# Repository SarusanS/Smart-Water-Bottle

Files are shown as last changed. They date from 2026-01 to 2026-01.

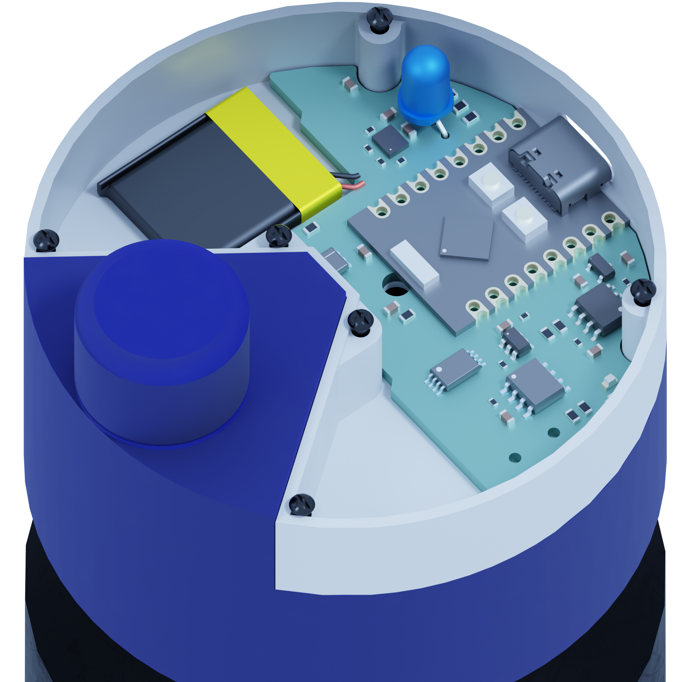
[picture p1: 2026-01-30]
RendersImaes_2/11.png

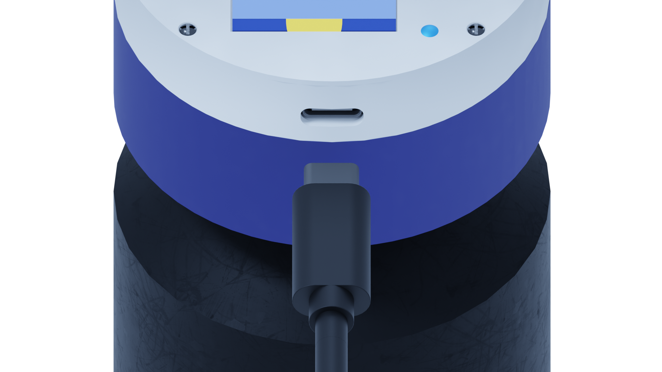
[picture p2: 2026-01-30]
RendersImages_1/6.png

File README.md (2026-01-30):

# Project Highlight | Product Design – Smart Water Bottle

This project presents a **standalone Smart Water Bottle** developed as part of a **Product Design course**, focused on accurate, motion-aware water consumption monitoring under real-world usage conditions such as **movement, refilling, and power interruptions**.

The system is **fully embedded** and operates independently **without requiring a mobile application**, prioritizing **reliability, usability, and data integrity**.

---

## System Functionality

Water consumption is monitored by tracking changes in liquid level using a **VL53L0X Time-of-Flight (ToF) distance sensor**. Instead of relying on the absolute bottle capacity, the system calculates consumed volume based on **successive stable distance measurements**, allowing cumulative tracking across multiple refill cycles.

Even if the physical bottle capacity is limited (e.g., **1 litre**), users can configure daily intake goals of **5 L, 10 L, or 15 L**. Each refill is automatically detected as an **increase in water level**, while subsequent decreases are accumulated to compute **total consumption over time**.  
This approach enables **continuous and scalable intake monitoring**, independent of bottle size.

---

## Motion-Aware Validation

To ensure measurement accuracy, the system integrates a **BMI270 Inertial Measurement Unit (IMU)** combined with a **Madgwick sensor fusion filter**.

- Distance measurements are accepted only when the bottle is **upright and stable**
- **Tilt, motion, shaking, lifting, and refilling events** are detected and filtered out
- A **stability verification delay** ensures readings are taken only after motion has fully stopped

This motion-aware logic prevents **false volume calculations** and significantly improves measurement reliability during **daily use**.

---

## Floating Reflective Marker for Accurate Measurement

To overcome the challenges of measuring water level in transparent containers, a **floating reflective marker** is used:

- A small **floating rubber disc** is placed directly on the water surface
- The ToF sensor reflects off the **rubber surface instead of the water itself**
- This avoids errors caused by **ripples, bubbles, refraction, or transparent bottle walls**

As the marker naturally follows the water surface, the system achieves **consistent and repeatable distance measurements**, which are converted into volume through **firmware-level calculations**.

---

## Operating Modes

### Mode 1 – Goal-Based Tracking
- User-configurable **daily intake goal**
- Tracks **daily water consumption**
- Automatically **resets every 24 hours**
- Stores **previous day’s consumption** for reference

### Mode 2 – Continuous Tracking
- No predefined intake goal
- Tracks **total consumption continuously**
- **Manual reset** via touch-based confirmation
- Suitable for **long-term or unrestricted monitoring**

---

## User Interface and Interaction

- Touch-based input supports **display wake-up, goal setting, mode switching, and reset confirmation**
- **OLED display** presents real-time information including:
  - Water consumption
  - Daily goal status
  - Operating mode
  - Battery voltage
  - Time and date
- **Automatic display sleep** minimizes power consumption

---

## Touch Gesture Instructions

The system uses a **capacitive touch interface** to provide intuitive, button-less user interaction. Different tap patterns are interpreted by firmware to trigger specific actions.

| Gesture | Action |
|---|---|
| Single Tap | Increment value during goal or setting configuration |
| Double Tap | Wake the display or confirm a selection |
| Triple Tap | Switch between operating modes (Goal-Based / Continuous) |
| Long Inactivity | Automatically puts the display into sleep mode |

Touch input is **debounced and time-window validated** in firmware to prevent false triggers and ensure reliable gesture detection.

---

## Power and Battery Management

- Battery voltage is monitored in real time using the **ESP32 ADC**
- Status is displayed directly on the **OLED interface**
- Safe charging is handled externally via a **dedicated battery charging circuit**
- **Persistent storage** ensures data integrity across power cycles, supporting portable operation

---

## Hardware and PCB Design

- Custom **SMD-based PCB** designed for compact, reliable, and production-ready assembly
- Optimized component placement for:
  - Distance sensor
  - IMU
  - OLED display
  - Power management circuitry
- Designed to support **robust, portable, and scalable product deployment**

---

## Data Integrity and Reliability

- All critical parameters and usage data are stored in **non-volatile flash memory (ESP32 NVS)**
- Seamless recovery after **unexpected power loss**
- **Noise-filtered distance averaging and outlier rejection** improve measurement accuracy

---

## Technology Stack

- **Microcontroller:** ESP32  
- **Sensors:** VL53L0X ToF Sensor, BMI270 IMU  
- **Sensor Fusion:** Madgwick Filter  
- **Display:** SSD1306 OLED  
- **Input:** Touch Interface  
- **Storage:** ESP32 Non-Volatile Storage (NVS)  
- **Hardware:** Custom SMD PCB Design  

---

## Learning Outcomes

This project significantly strengthened my skills in:

- Embedded firmware development  
- Sensor fusion and motion-aware measurement  
- Robust signal processing for real-world conditions  
- Power-aware system design  
- SMD PCB design and hardware integration  
- User-centric embedded product development

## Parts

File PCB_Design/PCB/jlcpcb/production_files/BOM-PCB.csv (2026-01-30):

Comment | Designator | Footprint | LCSC | Quantity
100 | R5 | R_0402_1005Metric | C25076 | 1
100k | R1,R11,R7,R8 | R_0402_1005Metric | C25741 | 4
100n | C2,C4,C5,C6,C7,C8 | C_0603_1608Metric | C14663 | 6
10k | R13 | R_0603_1608Metric | C25804 | 1
10u | C1,C3,C9 | C_0603_1608Metric | C96446 | 3
150 | R12 | R_0603_1608Metric | C22808 | 1
1k | R6 | R_0402_1005Metric | C11702 | 1
1k | R17,R18 | R_0603_1608Metric | C21190 | 2
220 | R14,R15,R16 | R_0603_1608Metric | C22962 | 3
2k | R4 | R_0402_1005Metric | C4109 | 1
2k2 | R10,R9 | R_0402_1005Metric | C25879 | 2
2k2 | R2 | R_0603_1608Metric | C4190 | 1
82k | R3 | R_0603_1608Metric | C23254 | 1
AO3400A | Q1 | SOT-23 | C20917 | 1
BMI270 | U5 | Bosch_LGA-14_3x2.5mm_P0.5mm | C2836813 | 1
DW01A | U4 | SOT-23-6 | C42380662 | 1
FS8205A | Q2 | FS8205A | C2830320 | 1
GREEN_LED | D3 | LED_0805_2012Metric | C5878902 | 1
LM393 | U2 | SOIC-8_3.9x4.9mm_P1.27mm | C7955 | 1
RED_LED | D2 | LED_0603_1608Metric | C2286 | 1
TP4056-42-ESOP8 | U3 | SOIC-8-1EP_3.9x4.9mm_P1.27mm_EP2.41x3.3mm | C22470410 | 1

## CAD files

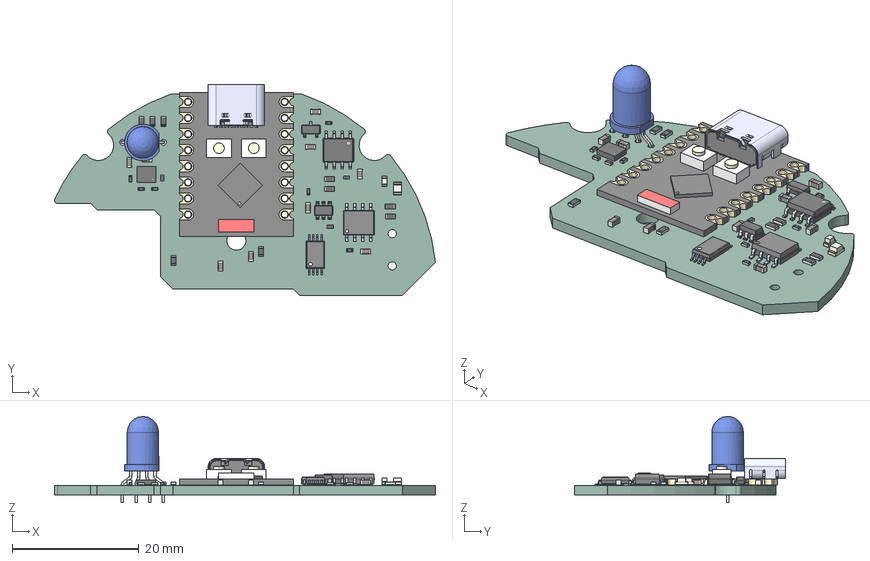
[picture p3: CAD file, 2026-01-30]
PCB_Design/PCB/PCB.step
60.1 x 33.3 x 13.6 mm
C_0603_1608Metric x 9
R_0603_1608Metric x 9
R_0402_1005Metric x 9
SOT-23-6
LED_0805_2012Metric
Bosch_LGA-14_3x2.5mm_P0.5mm
LED_0603_1608Metric
TP4056--3DModel-STEP-56544
SOT-23
LED_D5.0mm-4_RGB_Wide_Pins
SOIC-8_3.9x4.9mm_P1.27mm
Board c3mini
USB C
components (other)^ESP32-C3 SuperMini
FS8205A--3DModel-STEP-56544
PCB_PCB

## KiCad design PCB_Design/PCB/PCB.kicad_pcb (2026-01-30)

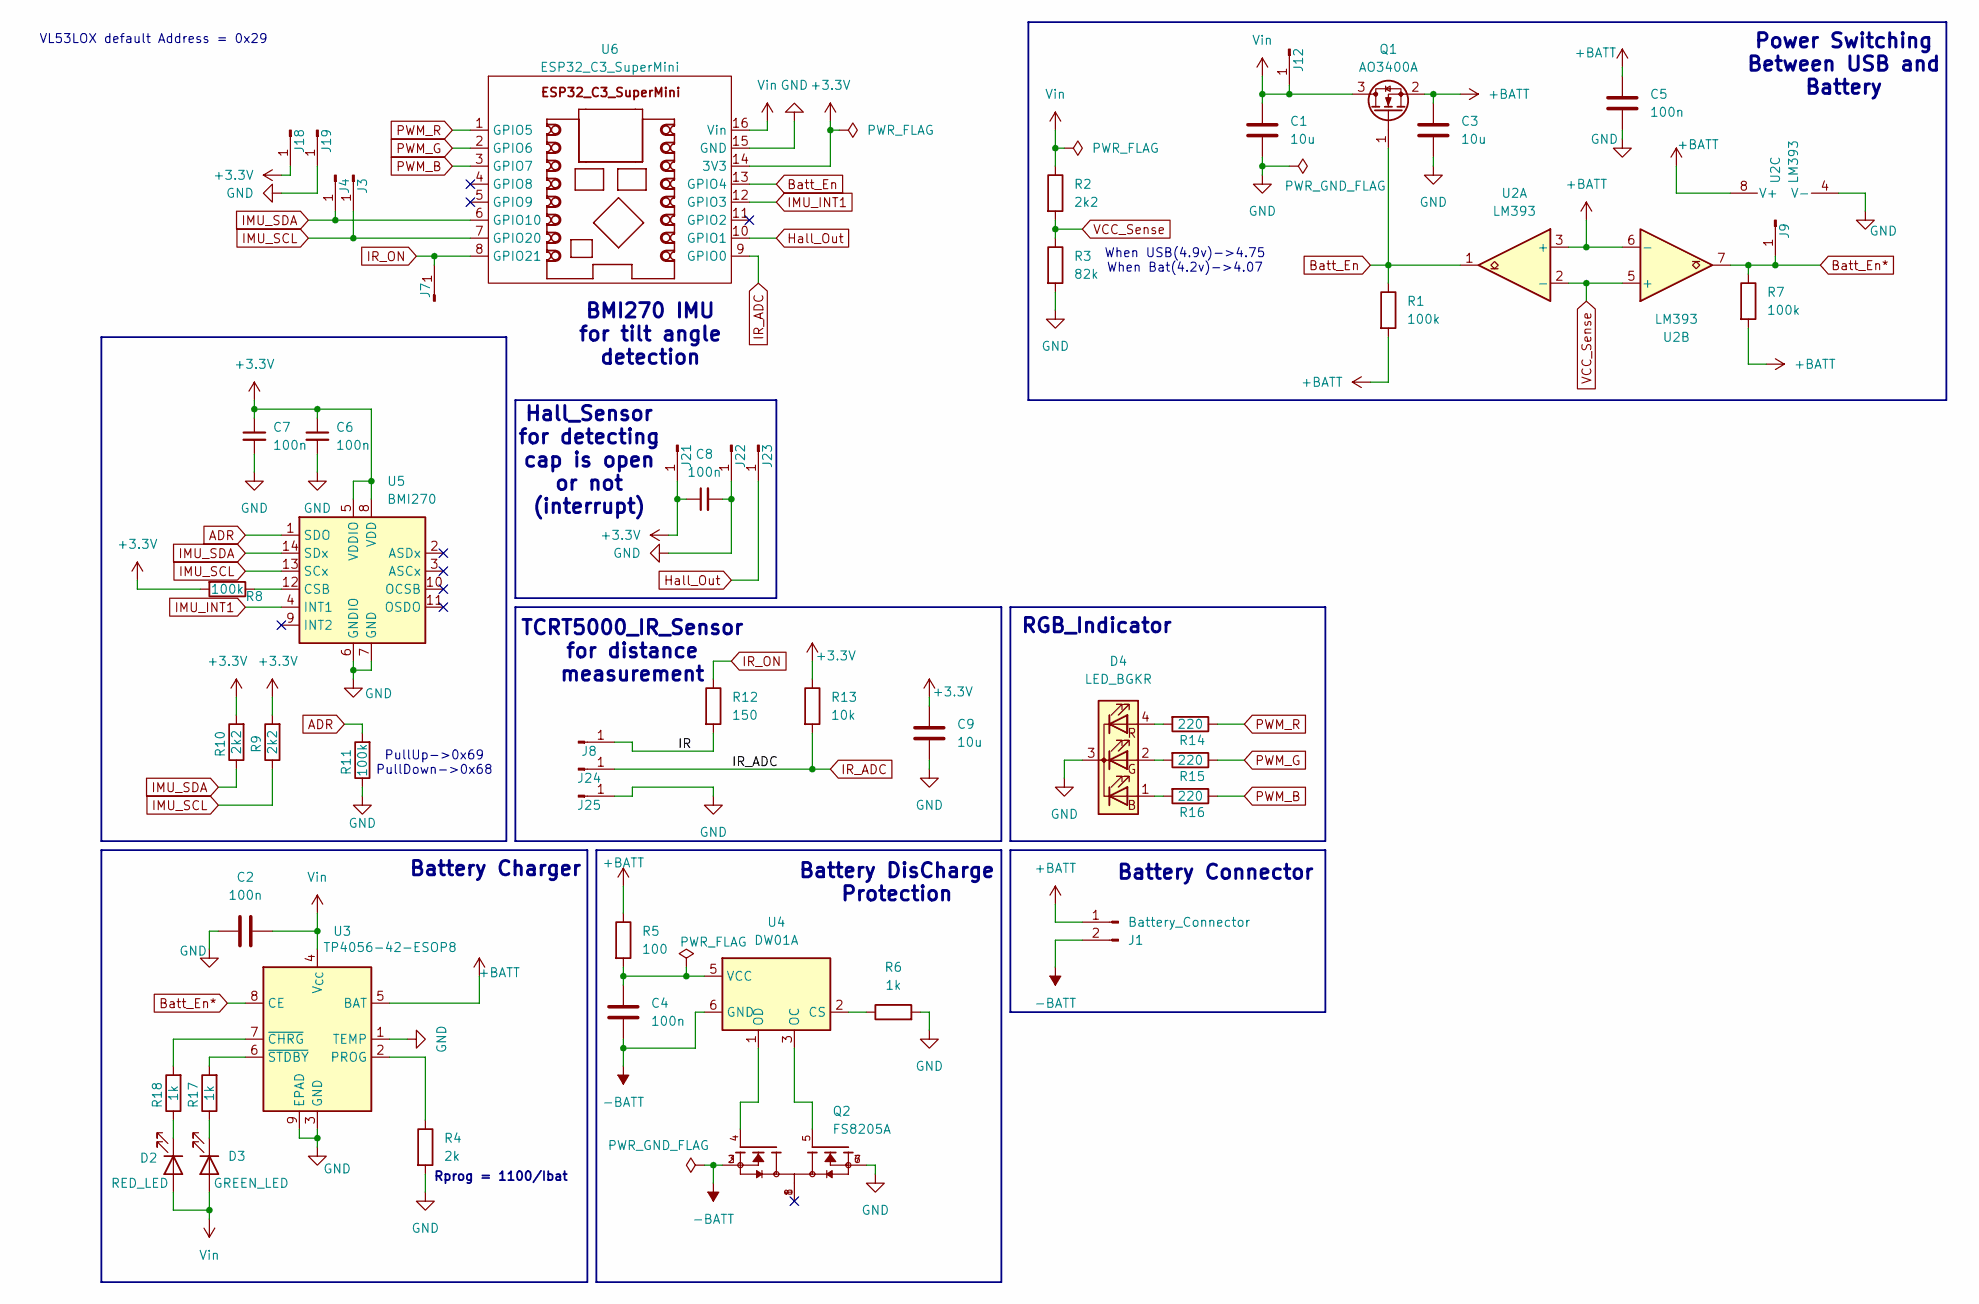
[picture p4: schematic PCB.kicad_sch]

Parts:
C1, C3, C9: 10u; C_0603_1608Metric
C2, C4, C5, C6, C7, C8: 100n; C_0603_1608Metric
D2: RED_LED; LED_0603_1608Metric
D3: GREEN_LED; LED_0805_2012Metric
D4: LED_BGKR; LED_D5.0mm-4_RGB_Wide_Pins_Bend_Horizontally
J1: Battery_Connector; TestPoint_2Pads_Pitch5.08mm_Drill1.3mm
J3, J4, J19, J22, J23, J24, J25: Conn_01x01_Pin; TestPoint_Pad_D1.5mm
J7: Conn_01x01_Pin; TestPoint_Pad_1.0x1.0mm
J8, J18, J21: Conn_01x01_Pin; TestPoint_Pad_1.5x1.5mm
J9, J12: Conn_01x01_Pin; TestPoint_Pad_D1.0mm
Q1: AO3400A; SOT-23
Q2: FS8205A; PARTREV 1.7
R1, R7, R8, R11: 100k; R_0402_1005Metric
R2: 2k2; R_0603_1608Metric
R3: 82k; R_0603_1608Metric
R4: 2k; R_0402_1005Metric
R5: 100; R_0402_1005Metric
R6: 1k; R_0402_1005Metric
R9, R10: 2k2; R_0402_1005Metric
R12: 150; R_0603_1608Metric
R13: 10k; R_0603_1608Metric
R14, R15, R16: 220; R_0603_1608Metric
R17, R18: 1k; R_0603_1608Metric
U2: LM393; SOIC-8_3.9x4.9mm_P1.27mm
U3: TP4056-42-ESOP8; SOIC-8-1EP_3.9x4.9mm_P1.27mm_EP2.41x3.3mm
U4: DW01A; SOT-23-6
U5: BMI270; Bosch_LGA-14_3x2.5mm_P0.5mm
U6: ESP32_C3_SuperMini

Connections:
+3.3V: C6.1, C7.1, C8.1, C9.1, J18.1, J21.1, R8.2, R9.2, R10.2, R13.1, U5.5 (VDDIO), U5.8 (VDD), U6.14 (3V3)
+BATT: C3.1, C5.1, J1.1, Q1.2 (S), R1.2, R5.1, R7.2, U2.3 (+), U2.6 (-), U2.8 (V+), U3.5 (BAT)
-BATT: C4.1, J1.2, Q2.2, Q2.3, U4.6 (GND)
/IR: J8.1, R12.2
ADR: R11.2, U5.1 (SDO)
Batt_En: Q1.1 (G), R1.1, U2.1, U6.13 (GPIO4)
Batt_En*: J9.1, R7.1, U2.7, U3.8 (CE)
GND: C1.2, C2.1, C3.2, C5.2, C6.2, C7.2, C8.2, C9.2, D4.3 (K), J19.1, J22.1, J25.1, Q2.6, Q2.7, R3.2, R4.2, R6.2, R11.1, U2.4 (V-), U3.1 (TEMP), U3.3 (GND), U3.9 (EPAD), U5.6 (GNDIO), U5.7 (GND), U6.15 (GND)
Hall_Out: J23.1, U6.10 (GPIO1)
IMU_INT1: U5.4 (INT1), U6.12 (GPIO3)
IMU_SCL: J3.1, R9.1, U5.13 (SCx), U6.7 (GPIO20)
IMU_SDA: J4.1, R10.1, U5.14 (SDx), U6.6 (GPIO10)
IR_ADC: J24.1, R13.2, U6.9 (GPIO0)
IR_ON: J7.1, R12.1, U6.8 (GPIO21)
unnamed: D2.1 (K), R18.1
unnamed: D3.1 (K), R17.1
unnamed: D4.1 (BA), R16.2
unnamed: D4.2 (GA), R15.2
unnamed: D4.4 (RA), R14.2
unnamed: R4.1, U3.2 (PROG)
unnamed: R18.2, U3.7 (~CHRG)
unnamed: R17.2, U3.6 (~STDBY)
unnamed: R6.1, U4.2 (CS)
unnamed: Q2.5, U4.3 (OC)
unnamed: Q2.4, U4.1 (OD)
unnamed: C4.2, R5.2, U4.5 (VCC)
unnamed: R8.1, U5.12 (CSB)
PWM_B: R16.1, U6.3 (GPIO7)
PWM_G: R15.1, U6.2 (GPIO6)
PWM_R: R14.1, U6.1 (GPIO5)
VCC_Sense: R2.2, R3.1, U2.2 (-), U2.5 (+)
Vin: C1.1, C2.2, D2.2 (A), D3.2 (A), J12.1, Q1.3 (D), R2.1, U3.4 (V_{CC}), U6.16 (Vin)

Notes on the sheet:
BMI270 IMU for tilt angle detection
PullUp->0x69 PullDown->0x68
Power Switching Between USB and Battery
Hall_Sensor for detecting cap is open or not (interrupt)
Battery Connector
When USB(4.9v)->4.75 When Bat(4.2v)->4.07
Battery DisCharge Protection
Rprog = 1100/Ibat
Battery Charger
VL53LOX default Address = 0x29
TCRT5000_IR_Sensor for distance measurement
RGB_Indicator

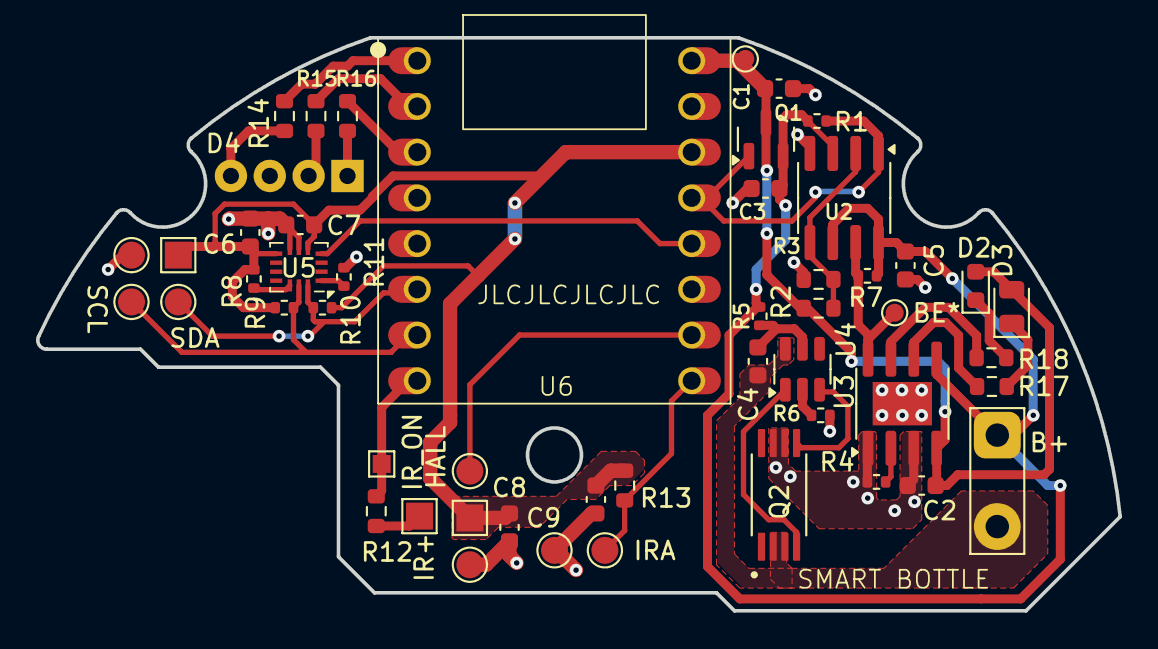
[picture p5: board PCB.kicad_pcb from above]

Board: 2 copper layers, 60.1 x 31.8 mm, 51 parts (0 on the bottom side), 32 nets.

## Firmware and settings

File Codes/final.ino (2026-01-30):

#include <Wire.h>
#include <Adafruit_GFX.h>
#include <Adafruit_SSD1306.h>
#include "Adafruit_VL53L0X.h"
#include "SparkFun_BMI270_Arduino_Library.h" 
#include <Adafruit_AHRS.h>                  

// --- CONSTANTS & CONFIGURATION ---
#define I2C_SDA_PIN 10
#define I2C_SCL_PIN 20
#define SCREEN_WIDTH 128
#define SCREEN_HEIGHT 64
#define OLED_RESET -1
const int TOUCH_PIN = 1;  
const int LED_PIN   = 2;  
const int analogPin = 4;

const unsigned long DEBOUNCE_MS = 40;
const unsigned long MULTI_GAP_MS = 300;
const unsigned long DISPLAY_TIMEOUT_MS = 15000;
const unsigned long SETTING_IDLE_TIMEOUT_MS = 3000;
const unsigned long IMU_READ_INTERVAL_MS = 20; 

const int SAMPLE_INTERVAL = 500;   
const int AVG_PERIOD = 10000;      
const int MAX_DEVIATION = 10;      
const float crossArea_dm2 = 0.4225; 
const float TILT_THRESHOLD_DEGREES = 10.0; 
const float STABILITY_CHANGE_THRESHOLD = 10.0; 
#define MAX_SAMPLES (AVG_PERIOD / SAMPLE_INTERVAL)
int samples[MAX_SAMPLES];

const unsigned long STABILITY_WAIT_MS = 15000; 

// --- GLOBAL OBJECTS ---
Adafruit_SSD1306 display(SCREEN_WIDTH, SCREEN_HEIGHT, &Wire, OLED_RESET);
Adafruit_VL53L0X lox = Adafruit_VL53L0X();
BMI270 imu;             
Adafruit_Madgwick filter; 

// --- GLOBAL STATE VARIABLES ---
int currentMode = 1; 
float initialdistance = 0;
float lastdistance = 0;
float lastAngleX = 0.0, lastAngleY = 0.0; 
bool prev_unstable = false;
unsigned long lastSensorReadTime = 0, stabilityCheckStartTime = 0; 
bool waitingForStability = false;

float volumeLimitLiters = 0.0, consumedVolume = 0.0; 
int settingValue = 0;
unsigned long lastvolumesettime = 0;
float lastdayremaing = 0, lastdayconsumbtion = 0;
float voltage = 0.0;

// Time tracking
unsigned long previousMillis = 0;
int hour = 0, minute = 0, second = 0;
int month = 1, day = 1, year = 2025;

// Initial Setup
bool isInitialSetup = true; 
int setupStep = 0; 

volatile int touchCount = 0;
unsigned long lastTouchTime = 0, lastDebounceTime = 0;
int lastStableState = LOW;
bool waitingForMore = false;
bool displayAwake = false, inSettingMode = false, alreadyreset = false;

// --- FUNCTION DECLARATIONS ---
void setupI2C(); void initOLED(); void initBMI270();
void updateIMUAngles(float& p, float& r);
bool isTilted(float p, float r); bool isStable(float p, float r);
float getAverageDistanceDM(); void updatevolume();
void handleVolumeSensing(unsigned long now); void handleTouch();
void classifyTouch(int count); void displaySleep();
void displayStatus(); void displayLimitSetting();
void displayModeSwitch(); void displayResetConfirmMode2();
void handleDisplayTimeout(); void dayreset();
void updateBatteryVoltage(); void updateClock();

// --- SETUP ---
void setup() {
  Serial.begin(9600);
  pinMode(TOUCH_PIN, INPUT);
  pinMode(LED_PIN, OUTPUT);
  
  setupI2C(); 
  Serial.println("I2C Bus Initialized.");
  initOLED();
  
  while (isInitialSetup) {
    handleTouch(); 
    display.clearDisplay();
    display.setTextSize(1);
    display.setTextColor(SSD1306_WHITE);
    display.setCursor(0, 0);
    display.println(" INITIAL TIME SETUP");
    display.drawFastHLine(0, 12, 128, 1);
    display.setCursor(0, 48); display.println("1:Set | 2:Next");
    display.setCursor(0, 56); display.println("3:Back");
    display.setTextSize(2);
    display.setCursor(0, 25);
    if (setupStep == 0)      display.printf("MONTH: %02d", month);
    else if (setupStep == 1) display.printf("DAY:   %02d", day);
    else if (setupStep == 2) display.printf("HOUR:  %02d", hour);
    else if (setupStep == 3) display.printf("MIN:   %02d", minute);
    display.display();
    delay(10); 
  }

  // --- GREETING & INITIALIZATION SCREEN ---
  display.clearDisplay();
  display.setTextSize(2);
  display.setTextColor(SSD1306_WHITE);
  display.setCursor(15, 20);
  display.println("WELCOME!");
  display.setTextSize(1);
  display.setCursor(15, 45);
  display.println("Initializing...");
  display.display();

  if (!lox.begin()) { Serial.println("❌ Failed to find VL53L0X sensor!"); }
  else { Serial.println("✅ VL53L0X sensor initialized!"); }
  
  initBMI270();
  filter.begin(50); 
  Serial.println("✅ BMI270 Checker Ready.");

  analogReadResolution(12);
  analogSetAttenuation(ADC_11db);
  
  delay(1500); 

  displayAwake = true;
  lastTouchTime = millis(); 

  initialdistance = getAverageDistanceDM();
  lastdistance = initialdistance;
  Serial.printf("Initial distance: %.2f dm\n", initialdistance);
  Serial.println("✅ System Ready (Sleep Mode)");
  previousMillis = millis(); 
}

void loop() {
  unsigned long now = millis();
  handleVolumeSensing(now);
  handleTouch();
  updateClock();
  
  if (displayAwake && !inSettingMode) displayStatus();
  handleDisplayTimeout();
  
  if (currentMode == 1) dayreset(); 
  delay(10); 
}

// --- TOUCH HANDLING ---
void handleTouch() {
  int raw = digitalRead(TOUCH_PIN);
  unsigned long now = millis();
  if (raw != lastStableState && now - lastDebounceTime >= DEBOUNCE_MS) {
    lastStableState = raw; lastDebounceTime = now;
    if (raw == HIGH) { touchCount++; waitingForMore = true; lastTouchTime = now; Serial.printf("Tap #%d detected\n", touchCount); }
  }
  if (waitingForMore && (now - lastTouchTime >= MULTI_GAP_MS)) {
    classifyTouch(touchCount); touchCount = 0; waitingForMore = false;
  }
}

void classifyTouch(int count) {
  if (isInitialSetup) {
    // if (count == 1) { if (++month > 12) month = 1; } 
    // else if (count == 2) { setupStep++; if (setupStep > 3) isInitialSetup = false; }
    // else if (count == 3) { setupStep--; if (setupStep < 0) setupStep = 0; }
    // return;

    if (count == 1) { // Single: Set
      if (setupStep == 0) { month++; if (month > 12) month = 1; }
      else if (setupStep == 1) { day++; if (day > 31) day = 1; }
      else if (setupStep == 2) { hour++; if (hour > 23) hour = 0; }
      else if (setupStep == 3) { minute++; if (minute > 59) minute = 0; }
    } 
    else if (count == 2) { // Double: Next
      setupStep++;
      if (setupStep > 3) isInitialSetup = false;
    }
    else if (count == 3) { // Triple: Back
      setupStep--;
      if (setupStep < 0) setupStep = 0;
    }
    return;
  }
  if (count == 1) { Serial.println("➡ Single Touch"); } 
  else if (count == 2 && !displayAwake) { Serial.println("➡ Double Touch - Wake Display"); displayAwake = true; inSettingMode = false; lastTouchTime = millis(); } 
  else if (count == 2 && displayAwake) { if (currentMode == 1) { Serial.println("➡ Double Touch - Goal Setting"); displayLimitSetting(); } else { Serial.println("➡ Double Touch - Reset Confirm"); displayResetConfirmMode2(); } } 
  else if (count == 3 && displayAwake) { Serial.println("➡ Triple Touch - Switch Mode"); displayModeSwitch(); }
}

// --- MENUS ---
void displayModeSwitch() {
  inSettingMode = true; int target = (currentMode == 1) ? 2 : 1; unsigned long start = millis();
  while (millis() - start < SETTING_IDLE_TIMEOUT_MS) {
    display.clearDisplay(); display.setCursor(0,0); display.println("   SWITCH MODE");
    display.drawFastHLine(0, 10, 128, 1); display.setCursor(0, 25); display.printf("To Mode %d?", target);
    display.setCursor(0, 45); display.println("Double Tap: OK"); display.display();
    int raw = digitalRead(TOUCH_PIN); unsigned long now = millis();
    if (raw == HIGH && now - lastDebounceTime > 150) { 
       static int localTap = 0; localTap++; lastDebounceTime = now;
       if (localTap >= 2) { currentMode = target; consumedVolume = 0; Serial.printf("Mode Changed to %d\n", currentMode); localTap = 0; break; }
       delay(200);
    }
    delay(10);
  }
  inSettingMode = false;
}

void displayResetConfirmMode2() {
  inSettingMode = true; unsigned long start = millis();
  while (millis() - start < SETTING_IDLE_TIMEOUT_MS) {
    display.clearDisplay(); display.setCursor(0, 10); display.println("  RESET TRACKING?");
    display.setCursor(0, 40); display.println("Double Tap: OK"); display.display();
    int raw = digitalRead(TOUCH_PIN); unsigned long now = millis();
    if (raw == HIGH && now - lastDebounceTime > 150) {
       static int localR = 0; localR++; lastDebounceTime = now;
       if (localR >= 2) { consumedVolume = 0; Serial.println("✅ Mode 2 Reset Confirmed"); localR = 0; break; }
       delay(200);
    }
  }
  inSettingMode = false;
}

void displayLimitSetting() {
  unsigned long lastInputTime = millis(); bool confirmed = false; int settingTouchCount = 0; unsigned long touchStart = 0; const unsigned long doubleTouchGap = 200; inSettingMode = true;
  while (inSettingMode) { 
    unsigned long now = millis(); int raw = digitalRead(TOUCH_PIN); static int lastState = LOW; static unsigned long lastDebounce = 0;
    if (raw != lastState && now - lastDebounce > 50) { lastState = raw; lastDebounce = now; if (raw == HIGH) { settingTouchCount++; touchStart = now; lastInputTime = now; } }
    if (settingTouchCount == 2 && (now - touchStart < doubleTouchGap)) { volumeLimitLiters = (float)settingValue; consumedVolume = 0; lastvolumesettime = millis(); confirmed = true; alreadyreset = false; break; }
    if (settingTouchCount == 1 && (now - touchStart > doubleTouchGap)) { settingValue++; if (settingValue > 15) settingValue = 0; settingTouchCount = 0; }
    if (now - lastInputTime > SETTING_IDLE_TIMEOUT_MS) { confirmed = false; break; }
    display.clearDisplay(); display.setTextSize(1); display.setCursor(0, 0); display.println("   SET DAILY GOAL (L) "); display.drawFastHLine(0, 10, 128, 1);
    display.setCursor(0, 14); display.println("1 Tap: Increment\n2 Taps: Confirm\nIdle 3s: Cancel");
    display.setTextSize(4); display.setCursor(30, 38); display.printf("%2d", settingValue); display.display(); delay(10);
  }
  display.clearDisplay(); display.setTextSize(2); display.setCursor(10, 20);
  if (confirmed) { display.printf("Saved: %dL", settingValue); Serial.printf("Goal Set to: %d L\n", settingValue); } else { display.println("Cancelled"); }
  display.display(); delay(1200); inSettingMode = false; displayAwake = true; lastTouchTime = millis();
}

// --- STATUS DISPLAY ---
void displayStatus() {
  updateBatteryVoltage();
  display.clearDisplay();
  display.setTextSize(1);
  display.setTextColor(1);
  display.setCursor(0, 0); display.printf("%02d:%02d", hour, minute); 
  display.setCursor(85, 0); display.printf("%02d/%02d", day, month); 
  int x = 54; display.drawRect(x, 0, 20, 10, 1); display.fillRect(x + 20, 3, 2, 4, 1); 
  if (voltage > 3.7) { display.fillRect(x+2, 2, 4, 6, 1); display.fillRect(x+8, 2, 4, 6, 1); display.fillRect(x+14, 2, 4, 6, 1); }
  else if (voltage > 3.6) { display.fillRect(x+2, 2, 4, 6, 1); display.fillRect(x+8, 2, 4, 6, 1); }
  else if (voltage >= 3.5) { display.fillRect(x+2, 2, 4, 6, 1); }
  display.drawFastHLine(0, 12, 128, 1);
  display.setTextSize(2);
  display.setCursor(0, 18);
  if (currentMode == 1) {
    display.printf("Goal:%.1f", volumeLimitLiters);
    if (consumedVolume >= volumeLimitLiters) { display.drawLine(110, 24, 113, 28, 1); display.drawLine(113, 28, 119, 18, 1); }
    display.setCursor(0, 34); display.printf("Used:%.1f", consumedVolume);
    display.setTextSize(1); display.setCursor(0, 52); display.printf("yes_con: %.1f L", lastdayconsumbtion);
  } else {
    display.println("Continuous");
    display.setCursor(0, 34); display.printf("Used:%.1f", consumedVolume);
    display.setTextSize(1); display.setCursor(0, 52); display.println("Mode 2: Tracking Mode");
  }
  display.display();
}

// --- CORE UTILS ---
void updateClock() {
  unsigned long cur = millis();
  while (cur - previousMillis >= 1000) { previousMillis += 1000; second++;
    if (second >= 60) { second = 0; minute++; if (minute >= 60) { minute = 0; hour++; if (hour >= 24) { hour = 0; day++; } } }
  }
}

void dayreset() {
  if (millis() - lastvolumesettime >= 86400000 && !alreadyreset) { 
    lastdayconsumbtion = consumedVolume; consumedVolume = 0; alreadyreset = true;
    Serial.println("✅ Daily consumption reset.");
  }
}

void handleVolumeSensing(unsigned long now) {
  float currentPitch, currentRoll;
  if (now - lastSensorReadTime >= IMU_READ_INTERVAL_MS) {
    updateIMUAngles(currentPitch, currentRoll);
    lastSensorReadTime = now;
    bool tilted = isTilted(currentPitch, currentRoll);
    bool stable = isStable(currentPitch, currentRoll);
    Serial.printf("Roll(X): %.2f deg | Pitch(Y): %.2f deg | Tilted: %s | Stable: %s\n",
                  currentRoll, currentPitch, tilted ? "TRUE" : "FALSE", stable ? "TRUE" : "FALSE");
    if (stable && !tilted) { lastAngleX = currentPitch; lastAngleY = currentRoll; }
    if (!stable || tilted) prev_unstable = true; 
    if (stable && !tilted && prev_unstable && !waitingForStability) {
      Serial.println("🔴🔴🔴Motion stopped. Starting stability verification🔴🔴🔴...");
      stabilityCheckStartTime = now; waitingForStability = true;
    }
  }
  if (waitingForStability && (now - stabilityCheckStartTime >= STABILITY_WAIT_MS)) {
    Serial.println("🔴Wait period elapsed. Verifying stability again...");
    float vPitch, vRoll; updateIMUAngles(vPitch, vRoll);
    if (isStable(vPitch, vRoll) && !isTilted(vPitch, vRoll)) {
        Serial.println("✅ Stability confirmed. Updating volume calculation");
        updatevolume(); prev_unstable = false; 
    } else { Serial.println("❌❌❌ Still tilted or unstable, skipping update."); }
    waitingForStability = false; 
  }
}

void updatevolume() {
  float current_distance = getAverageDistanceDM();
  float delta_distance = current_distance - lastdistance;
  float delta_volume = delta_distance * crossArea_dm2;
  Serial.printf("Current: %.2f dm | Last: %.2f dm | Δ: %.3f dm\n", current_distance, lastdistance, delta_distance);
  if (delta_distance > 0.05) { consumedVolume += delta_volume; Serial.printf("💧 Water consumed. Volume +%.3f dm³ | Total consumed: %.3f dm³\n", delta_volume, consumedVolume); } 
  else if (delta_distance < -0.2) { Serial.println("🔄 Bottle refilled."); } 
  lastdistance = current_distance;
}

float getAverageDistanceDM() {
  unsigned long startTime = millis(); int sampleCount = 0;
  while (millis() - startTime < AVG_PERIOD) {
    updateClock(); VL53L0X_RangingMeasurementData_t measure; lox.rangingTest(&measure, false);
    if (measure.RangeStatus != 4 && sampleCount < MAX_SAMPLES) { samples[sampleCount++] = measure.RangeMilliMeter; }
    unsigned long waitStart = millis(); while(millis() - waitStart < SAMPLE_INTERVAL) { updateClock(); delay(5); }
  }
  if (sampleCount == 0) return lastdistance;
  long sum = 0; for (int i = 0; i < sampleCount; i++) sum += samples[i];
  float mean = (float)sum / sampleCount;
  long filteredSum = 0; int filteredCount = 0;
  for (int i = 0; i < sampleCount; i++) { if (abs(samples[i] - mean) <= MAX_DEVIATION) { filteredSum += samples[i]; filteredCount++; } }
  float avg_mm = (filteredCount > 0) ? (float)filteredSum / filteredCount : mean;
  Serial.printf("✅ Averaged Distance: %.1f mm\n", avg_mm);
  return avg_mm / 100.0;
}

void setupI2C() { Wire.begin(I2C_SDA_PIN, I2C_SCL_PIN); }
void initOLED() { if (!display.begin(SSD1306_SWITCHCAPVCC, 0x3C)) while(1); display.clearDisplay(); display.display(); }
void initBMI270() { if (imu.beginI2C(BMI2_I2C_PRIM_ADDR) != BMI2_OK) { Serial.println("ERROR: BMI270 not found."); while(1); } imu.performComponentRetrim(); imu.performAccelOffsetCalibration(BMI2_GRAVITY_POS_Z); imu.performGyroOffsetCalibration(); }
void updateIMUAngles(float& p, float& r) { imu.getSensorData(); filter.updateIMU(imu.data.gyroX, imu.data.gyroY, imu.data.gyroZ, imu.data.accelX, imu.data.accelY, imu.data.accelZ); p = filter.getPitch(); r = filter.getRoll(); }
bool isTilted(float p, float r) { return (abs(p) > TILT_THRESHOLD_DEGREES || abs(r) > TILT_THRESHOLD_DEGREES); }
bool isStable(float p, float r) { float dp = abs(p - lastAngleX), dr = abs(r - lastAngleY); return (dp < STABILITY_CHANGE_THRESHOLD && dr < STABILITY_CHANGE_THRESHOLD && abs(sqrt(imu.data.accelX*imu.data.accelX+imu.data.accelY*imu.data.accelY+imu.data.accelZ*imu.data.accelZ)-1.0)<0.1); }
void updateBatteryVoltage() { voltage = (analogRead(analogPin) / 4095.0) * 2.89 * 1.33; }
void handleDisplayTimeout() { if (displayAwake && !inSettingMode && (millis() - lastTouchTime > DISPLAY_TIMEOUT_MS)) { display.clearDisplay(); display.display(); displayAwake = false; } }
void displaySleep() { display.clearDisplay(); display.display(); }

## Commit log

2026-01-30 All Necessary Files are uploaded
    [BOM-PCB.csv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]
2026-01-30 Add project details for Smart Water Bottle
    Added detailed project overview and system functionality for the Smart Water Bottle, including motion-aware validation, user interface, power management, and technology stack.
